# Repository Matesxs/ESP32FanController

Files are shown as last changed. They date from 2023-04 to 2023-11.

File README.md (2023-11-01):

# ESP32 PWM Fan Controller

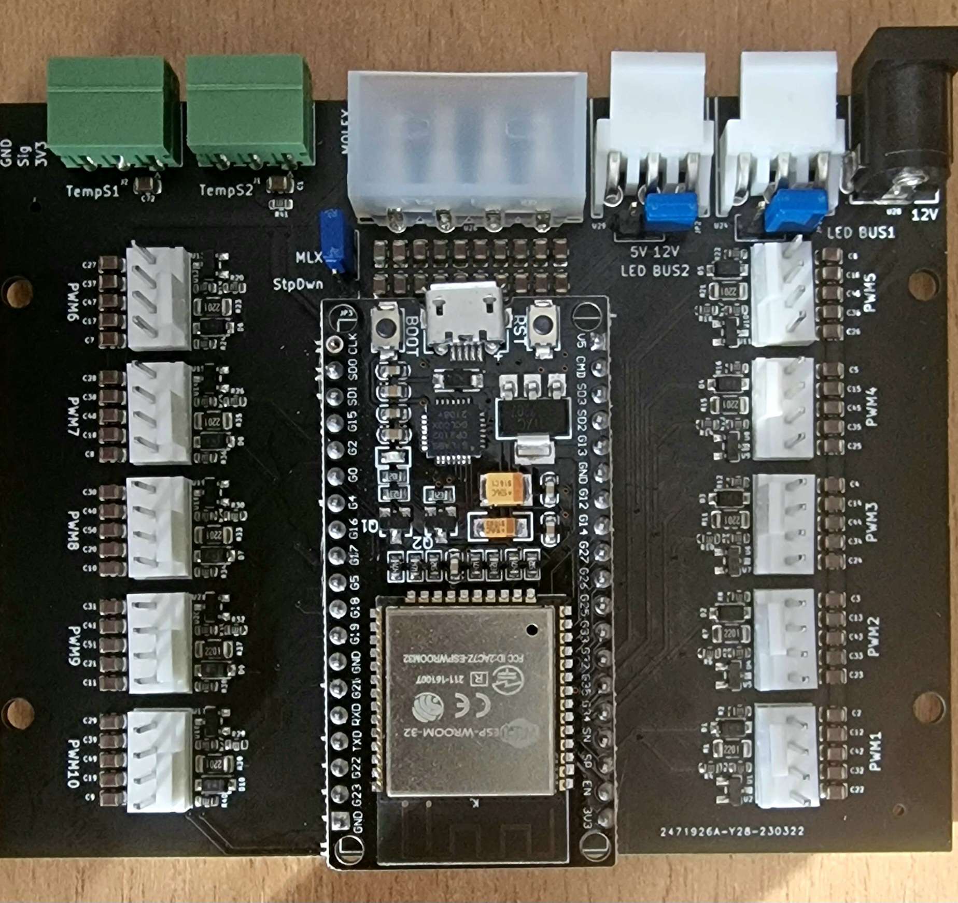
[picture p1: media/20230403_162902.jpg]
Image of final board


## Description
### This project is still in development so lot of things can be untested or not working at all!

```text
ESP32 10 channel pwm fan controller with control over tcp sockets and serial, 
temperature readout from onewire temperature probes (unlimited count, board have 2 ports), 
fan control routine (automatic - 20 points temperature curves with option of multiple 
temperature inputs and one external temperature value set by control interfaces, manual) 
for 10 separated channels with rpm readout from tacho sensor and led strip control routine with 
predefined effects (some of them use the temperature probes to be able to display temperature).
```

## Features

* 10 Channels for PWM fans
  * Automatic or manual fan speed control
  * Automatic control with 20 point curves with option for multi source temperature input for each fan
* 2 Channels for one wire temperature probes
* 2 Channels for RGB adressable led strips
  * Predefined effects and some even reacts to temperature
  * Support for both 5V and 12V warriants
* Integration for Argus Monitor
* Power by molex or barrel jack (selectable by jumper when stepdown is present)

## Todo

- [x] Publish Schematics for board

## References

[ESP32 Docs](https://docs.espressif.com/projects/esp-idf/en/latest/esp32/) \
[PlatformIO](https://platformio.org) \
[NeoPixelBus](https://github.com/Makuna/NeoPixelBus) \
[Argus Monitor](https://www.argusmonitor.com) \
[Argus Monitor Controller example](https://github.com/openfancontrol/arguscontroller) \
[DallasTemperature](https://github.com/milesburton/Arduino-Temperature-Control-Library) \
[ArduinoJson](https://github.com/bblanchon/ArduinoJson)

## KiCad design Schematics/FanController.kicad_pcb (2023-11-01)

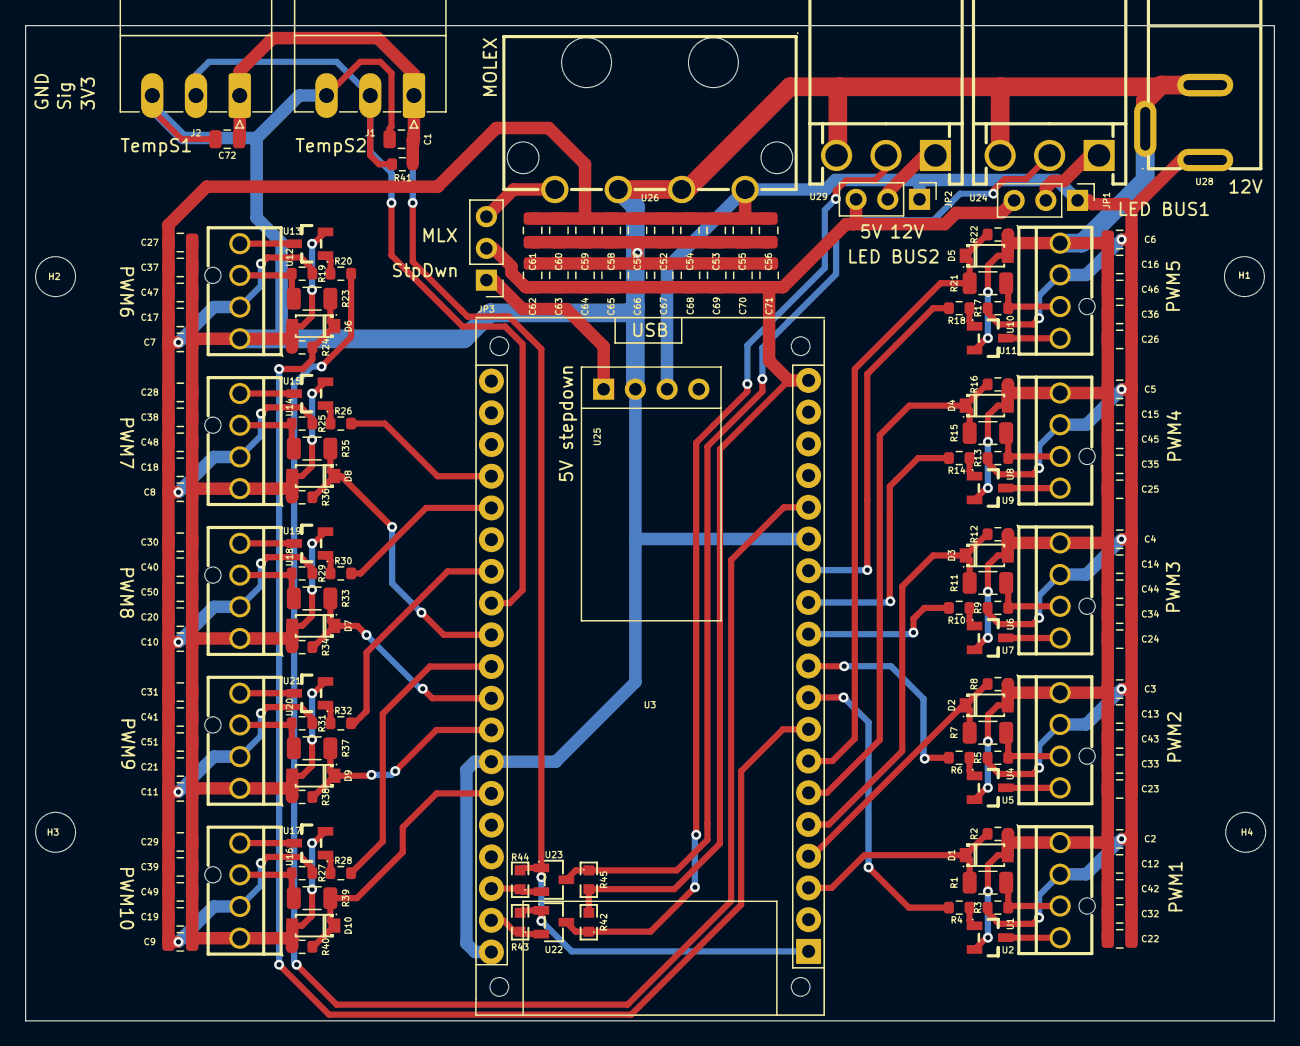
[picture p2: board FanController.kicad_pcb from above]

Board: 2 copper layers, 100.0 x 79.7 mm, 164 parts (0 on the bottom side), 63 nets.

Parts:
C1, C2, C3, C4, C5, C6, C7, C8, C9, C10, C11, C12, C13, C14, C15, C16, C17, C18, C19, C20, C21, C22, C23, C24, C25, C26, C27, C28, C29, C30, C31, C32, C33, C34, C35, C36, C37, C38, C39, C40, C41, C42, C43, C44, C45, C46, C47, C48, C49, C50, C51, C52, C53, C54, C55, C56, C57, C58, C59, C60, C61, C62, C63, C64, C65, C66, C67, C68, C69, C70, C71, C72: 10u; C_0805_2012Metric
D1, D2, D3, D4, D5, D6, D7, D8, D9, D10: BZT52C3V3; SOD-123_L2.8-W1.8-LS3.7-RD
H1, H2, H3, H4: MountingHole; MountingHole_3.2mm_M3_DIN965
J1: TempSensor1; PhoenixContact_MC_1,5_3-G-3.5_1x03_P3.50mm_Horizontal
J2: TempSensor2; PhoenixContact_MC_1,5_3-G-3.5_1x03_P3.50mm_Horizontal
JP1, JP2: Jumper_3_Open; PinHeader_1x03_P2.54mm_Vertical
JP3: 5V selector; PinHeader_1x03_P2.54mm_Vertical
R1, R7, R11, R15, R21, R23, R33, R35, R37, R39: 2k2; R_1206_3216Metric
R2, R3, R4, R5, R6, R8, R9, R10, R12, R13, R14, R16, R17, R18, R19, R20, R22, R24, R25, R26, R27, R28, R29, R30, R31, R32, R34, R36, R38, R40, R41: 3k3; R_0603_1608Metric
R42, R43, R44, R45: 0603WAF8201T5E; R0603
U1, U4, U6, U8, U10, U12, U14, U16, U18, U20: Fan1; CONN-TH_47053-1000
U2, U5, U7, U9, U11, U13, U15, U17, U19, U21: BC847B,215; SOT-23-3_L2.9-W1.6-P1.90-LS2.8-TL
U3: ES32-DevKitC; MODULE_ESP32-DEVKITC-32D
U22, U23: BSS138; SOT-23-3_L2.9-W1.3-P1.90-LS2.4-BR
U24, U29: S3P-VH(LF)(SN); CONN-TH_3P-P3.96_S3P-VH-LF-SN
U25: STPDWN3V3; ESP32_STPDWN5V
U26: M5082RK-04P; CONN-TH_M5082RK-04P
U28: DC-005_5_5-2_0MM; DC-IN-TH_DC-5520-1

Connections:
+3V3: C1.1, C72.1, J1.1, J2.1, R41.1, R43.2, R44.2, U3.1 (3V3), U22.1 (G), U23.1 (G)
+5V: C62.1, C63.1, C64.1, C65.1, C66.1, C67.1, C68.1, C69.1, C70.1, C71.1, JP1.3 (B), JP2.3 (B), JP3.2 (C), R42.2, R45.2, U3.19 (5V)
+12V: C2.1, C3.1, C4.1, C5.1, C6.1, C7.1, C8.1, C9.1, C10.1, C11.1, C12.1, C13.1, C14.1, C15.1, C16.1, C17.1, C18.1, C19.1, C20.1, C21.1, C22.1, C23.1, C24.1, C25.1, C26.1, C27.1, C28.1, C29.1, C30.1, C31.1, C32.1, C33.1, C34.1, C35.1, C36.1, C37.1, C38.1, C39.1, C40.1, C41.1, C42.1, C43.1, C44.1, C45.1, C46.1, C47.1, C48.1, C49.1, C50.1, C51.1, C52.1, C53.1, C54.1, C55.1, C56.1, C57.1, C58.1, C59.1, C60.1, C61.1, JP1.1 (A), JP2.1 (A), R3.1, R5.1, R9.1, R13.1, R17.1, R19.1, R25.1, R27.1, R29.1, R31.1, U1.2, U4.2, U6.2, U8.2, U10.2, U12.2, U14.2, U16.2, U18.2, U20.2, U25.3 (VIN), U26.1, U28.4
/FAN_Interface1/DI_Tach/IN: R5.2, R7.1, U4.3
/FAN_Interface1/PWM: R6.2, U3.10 (IO26)
/FAN_Interface1/TACH: D2.1 (K), R7.2, R8.1, U3.4 (SVN)
/FAN_Interface2/DI_Tach/IN: R9.2, R11.1, U6.3
/FAN_Interface2/PWM: R10.2, U3.11 (IO27)
/FAN_Interface2/TACH: D3.1 (K), R11.2, R12.1, U3.5 (IO34)
/FAN_Interface3/DI_Tach/IN: R13.2, R15.1, U8.3
/FAN_Interface3/PWM: R14.2, U3.12 (IO14)
/FAN_Interface3/TACH: D4.1 (K), R15.2, R16.1, U3.6 (IO35)
/FAN_Interface4/DI_Tach/IN: R17.2, R21.1, U10.3
/FAN_Interface4/PWM: R18.2, U3.13 (IO12)
/FAN_Interface4/TACH: D5.1 (K), R21.2, R22.1, U3.7 (IO32)
/FAN_Interface5/DI_Tach/IN: R19.2, R23.1, U12.3
/FAN_Interface5/PWM: R20.2, U3.15 (IO13)
/FAN_Interface5/TACH: D6.1 (K), R23.2, R24.1, U3.8 (IO33)
/FAN_Interface6/DI_Tach/IN: R25.2, R35.1, U14.3
/FAN_Interface6/PWM: R26.2, U3.23 (IO15)
/FAN_Interface6/TACH: D8.1 (K), R35.2, R36.1, U3.28 (IO17)
/FAN_Interface7/DI_Tach/IN: R29.2, R33.1, U18.3
/FAN_Interface7/PWM: R30.2, U3.24 (IO2)
/FAN_Interface7/TACH: D7.1 (K), R33.2, R34.1, U3.30 (IO18)
/FAN_Interface8/DI_Tach/IN: R31.2, R37.1, U20.3
/FAN_Interface8/PWM: R32.2, U3.26 (IO4)
/FAN_Interface8/TACH: D9.1 (K), R37.2, R38.1, U3.31 (IO19)
/FAN_Interface9/DI_Tach/IN: R27.2, R39.1, U16.3
/FAN_Interface9/PWM: R28.2, U3.29 (IO5)
/FAN_Interface9/TACH: D10.1 (K), R39.2, R40.1, U3.33 (IO21)
/FAN_Interface/DI_Tach/IN: R1.1, R3.2, U1.3
/FAN_Interface/PWM: R4.2, U3.9 (IO25)
/FAN_Interface/TACH: D1.1 (K), R1.2, R2.1, U3.3 (SVP)
GND: C1.2, C2.2, C3.2, C4.2, C5.2, C6.2, C7.2, C8.2, C9.2, C10.2, C11.2, C12.2, C13.2, C14.2, C15.2, C16.2, C17.2, C18.2, C19.2, C20.2, C21.2, C22.2, C23.2, C24.2, C25.2, C26.2, C27.2, C28.2, C29.2, C30.2, C31.2, C32.2, C33.2, C34.2, C35.2, C36.2, C37.2, C38.2, C39.2, C40.2, C41.2, C42.2, C43.2, C44.2, C45.2, C46.2, C47.2, C48.2, C49.2, C50.2, C51.2, C52.2, C53.2, C54.2, C55.2, C56.2, C57.2, C58.2, C59.2, C60.2, C61.2, C62.2, C63.2, C64.2, C65.2, C66.2, C67.2, C68.2, C69.2, C70.2, C71.2, C72.2, D1.2 (A), D2.2 (A), D3.2 (A), D4.2 (A), D5.2 (A), D6.2 (A), D7.2 (A), D8.2 (A), D9.2 (A), D10.2 (A), J1.3, J2.3, R2.2, R8.2, R12.2, R16.2, R22.2, R24.2, R34.2, R36.2, R38.2, R40.2, U1.1, U2.2, U3.14 (GND), U3.32 (GND), U3.38 (GND), U4.1, U5.2, U6.1, U7.2, U8.1, U9.2, U10.1, U11.2, U12.1, U13.2, U14.1, U15.2, U16.1, U17.2, U18.1, U19.2, U20.1, U21.2, U24.3, U25.2 (GND), U26.2, U26.3, U28.2, U28.3, U29.3
unnamed: J1.2, J2.2, R41.2, U3.27 (IO16)
unnamed: JP1.2 (C), U24.1
unnamed: JP2.2 (C), U29.1
unnamed: JP3.1 (A), U25.1 (VO+)
unnamed: JP3.3 (B), U26.4
unnamed: R4.1, U2.1
unnamed: R6.1, U5.1
unnamed: R10.1, U7.1
unnamed: R14.1, U9.1
unnamed: R18.1, U11.1
unnamed: R20.1, U13.1
unnamed: R26.1, U15.1
unnamed: R28.1, U17.1
unnamed: R30.1, U19.1
unnamed: R32.1, U21.1
unnamed: U1.4, U2.3
unnamed: U4.4, U5.3
unnamed: U6.4, U7.3
unnamed: U8.4, U9.3
unnamed: U10.4, U11.3
unnamed: U12.4, U13.3
unnamed: U14.4, U15.3
unnamed: U16.4, U17.3
unnamed: U18.4, U19.3
unnamed: U20.4, U21.3
unnamed: R42.1, U22.3 (D), U29.2
unnamed: R43.1, U3.37 (IO23), U22.2 (S)
unnamed: R45.1, U23.3 (D), U24.2
unnamed: R44.1, U3.36 (IO22), U23.2 (S)

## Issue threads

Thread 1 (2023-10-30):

PCB design

suda, 2023-10-30:
Hi Martin, thank you for this project!
Would love to make my own but I'm missing the PCB/schematics. Could you share them as well?

Matesxs, 2023-11-01:
Sorry for delay, schematics were added in commit beeffa3

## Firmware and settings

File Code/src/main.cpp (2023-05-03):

#include "settings.h"

#include <Arduino.h>

#ifdef WIFI_CONNECTION
#ifdef CUSTOM_DNS
#include <ESPmDNS.h>
#endif

#include "connection/wifiHandling.h"

#ifdef ENABLE_OTA
#include "mic/OTA.h"
#endif

#ifdef WIFI_CONTROL
#include "communication/tcp_server.h"
#endif
#endif

#ifdef COM_SERIAL
#ifdef USE_ARGUS_INTERFACE
#include "communication/argus_com.h"
#endif
#endif

#ifdef LED_STRIPS_ENABLE
#include "led_strips/led_strips_handling_routine.h"
#include "led_strips/effects.h"
#endif

#include "mic/debug.h"
#include "pins.h"
#include "mic/data_share.h"
#include "tacho.h"
#include "temperature_reader.h"
#include "fan_control_loop.h"
#include "communication/message_processing.h"
#include "communication/communication_handler.h"

void setup()
{
#ifdef COM_SERIAL
  if (COM_SERIAL != Serial)
  {
    Serial.begin(115200);
    while (!Serial);
  }

#ifndef USE_ARGUS_INTERFACE
  COM_SERIAL.begin(115200);
  while (!COM_SERIAL);
#else
  COM_SERIAL.begin(57600);
  while (!COM_SERIAL);
#endif
#endif

  mainSettings.begin("main_settings", false);
  curvesStore.begin("curves", false);
  delay(50);

#ifdef WIFI_CONNECTION
  wifi_setup();
  wifi_setCredentials(mainSettings.isKey("wifi_ssid") ? mainSettings.getString("wifi_ssid", "").c_str() : "", mainSettings.isKey("wifi_pass") ? mainSettings.getString("wifi_pass", "").c_str() : "");
  wifi_enable();
#ifdef ENABLE_OTA
  OTA_setup();
#endif

#ifdef CUSTOM_DNS
  if (!MDNS.begin(mainSettings.isKey("dns_name") ? mainSettings.getString("dns_name", DEFAULT_DNS_NAME).c_str() : DEFAULT_DNS_NAME)) 
  {
    DEBUG("[MDNS] Error setting up MDNS responder!\r\n");
  }
#endif
#endif

#ifdef LED_STRIPS_ENABLE
  if (mainSettings.isKey("led_ch1_c"))
  {
    uint16_t numberOfLeds = mainSettings.getUShort("led_ch1_c", 10);

    DEBUG("[Main] Found led strip channel settings for channel 1 (%d)\r\n", numberOfLeds);

    ledStripChannel1 = new StripHandler(numberOfLeds, LED_STRIP1_DATA_PIN);

    if (mainSettings.isKey("led_ch1_m"))
    {
      DEBUG("[Main] Found led strip effect settings for channel 1\r\n");

      ledStripChannel1->setTarget(mainSettings.getString("led_ch1_m"));
    }
  }

  if (mainSettings.isKey("led_ch2_c"))
  {
    uint16_t numberOfLeds = mainSettings.getUShort("led_ch2_c", 10);

    DEBUG("[Main] Found led strip channel settings for channel 2 (%d)\r\n", numberOfLeds);

    ledStripChannel2 = new StripHandler(numberOfLeds, LED_STRIP2_DATA_PIN);

    if (mainSettings.isKey("led_ch2_m"))
    {
      DEBUG("[Main] Found led strip effect settings for channel 2\r\n");

      ledStripChannel2->setTarget(mainSettings.getString("led_ch2_m"));
    }
  }
#endif

  for (size_t i = 0; i < FAN_COUNT; i++)
  {
    auto pinSettings = FAN_PINS_HOLDER[i];
    pinMode(pinSettings.tachoPin, INPUT);
    pinMode(pinSettings.pwmPin, OUTPUT);
    ledcSetup(pinSettings.pwmChannel, FAN_PWM_FREQ, FAN_PWM_RES);
    ledcAttachPin(pinSettings.pwmPin, pinSettings.pwmChannel);
    ledcWrite(pinSettings.pwmChannel, MAX_FAN_PWM_VALUE);
    
    fanData[i].lerper.setReference(&fanData[i].currentPower);
    
    String key(i);

    if (curvesStore.isKey(key.c_str()))
    {
      DEBUG("[Main] Found curve for fan %d\r\n", i);

      if (curvesStore.getBytes(key.c_str(), static_cast<void*>(&fanData[i].curve), sizeof(TemperatureCurve)) != sizeof(TemperatureCurve))
        fanData[i].curve.setConstant(DEFAULT_PWM_PERCENT);
    }
    else
      fanData[i].curve.setConstant(DEFAULT_PWM_PERCENT);
      
    fanData[i].curve.sort();
    fanData[i].dirty = true;
  }

  tacho_begin();
  temp_read_begin();
  begin_fan_control();
#ifdef WIFI_CONNECTION
#ifdef WIFI_CONTROL
  begin_tcp_server();
#endif
#endif

#ifdef LED_STRIPS_ENABLE
  begin_led_strips();
#endif

#ifdef COM_SERIAL
#ifdef USE_ARGUS_INTERFACE
  begin_argus_com();
#endif
#endif

  begin_communication();
}

void loop()
{
  vTaskDelete(NULL);
}

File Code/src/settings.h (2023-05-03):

#pragma once

#include <Arduino.h>

// Functions settings
// #define USE_ARGUS_INTERFACE
#define COM_SERIAL Serial

#define WIFI_CONNECTION
#define WIFI_CONTROL
#define CUSTOM_DNS
#define DEFAULT_DNS_NAME "esp32_fan_controler"
#define LED_STRIPS_ENABLE

// Fan pwm settings
#define FAN_PWM_FREQ 1000
#define FAN_PWM_RES 10
const uint16_t MAX_FAN_PWM_VALUE = pow(2, FAN_PWM_RES) - 1;
const double DEFAULT_PWM_PERCENT = 25.0;

// Tacho settings
#define SAMPLES_PER_RPM_READING 5
#define FAN_PULSES_PER_ROTATION 2
#define FAN_NUMBER_OF_POLES 1

// Fan Control loop
#define FAN_SPEED_RAMP_TIME_DIRTY_MS 1000
#define FAN_SPEED_RAMP_TIME_MS 5000
#define TEMPERATURE_HYSTERESIS 2.0

// Mic
#define ARGUS_DEVICE_ID 1

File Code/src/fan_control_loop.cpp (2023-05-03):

#include "fan_control_loop.h"

#include <Arduino.h>

#include "pins.h"
#include "mic/data_share.h"
#include "settings.h"
#include "temperature_reader.h"
#include "mic/debug.h"

void fan_speed_control_task(void *)
{
  while (true)
  {
    for (size_t i = 0; i < FAN_COUNT; i++)
    {
      if (!fanData[i].manual)
      {
        float sourceTemp = temperatureFromSource(fanData[i].curve.tempSource);
        
        if (fanData[i].dirty || abs(fanData[i]._powerTemperature - sourceTemp) > TEMPERATURE_HYSTERESIS)
        {
          double targetPower = fanData[i].curve.eval(sourceTemp);
          fanData[i].lerper.set(targetPower, fanData[i].dirty ? FAN_SPEED_RAMP_TIME_DIRTY_MS : FAN_SPEED_RAMP_TIME_MS);

          DEBUG("[Fan Temperature Control] Evaluating temperature curve for fan %d to %.2f target power\r\n", i, targetPower);

          fanData[i].dirty = false;
          fanData[i]._powerTemperature = sourceTemp;
        }
      }

      if (!fanData[i].lerper.finished())
      {
        auto pinSettings = FAN_PINS_HOLDER[i];
        fanData[i].lerper.update();

        auto pwmValue = static_cast<uint32_t>(map(fanData[i].currentPower, 0.0, 100.0, static_cast<double>(MAX_FAN_PWM_VALUE), 0.0));
        DEBUG("[Fan Speed Control] Setting speed for fan %d to %.2f (%d)\r\n", i, fanData[i].currentPower, pwmValue);

        ledcWrite(pinSettings.pwmChannel, pwmValue);
      }
    }

    vTaskDelay(pdMS_TO_TICKS(50));
  }
}

void begin_fan_control()
{
  xTaskCreateUniversal(fan_speed_control_task, "fan_contrl", 4096, NULL, 1, NULL, 0);
}
